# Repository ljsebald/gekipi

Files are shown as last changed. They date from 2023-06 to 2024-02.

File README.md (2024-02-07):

# GekiPi

A controller for games such as O.N.G.E.K.I. based around the Raspberry Pi Pico.

Please note that this is still a Work-In-Progress and isn't really meant for
anyone to actually try to use just yet.

## License

The code in the firmware directory is covered by the MIT License. See
`COPYING.MIT` for more information.

The hardware design in the board directory is covered by the CERN Open Hardware
License Version 2 - Strongly Reciprocal (CERN-OHL-S). See `cern_ohl_s_v2.txt`
for more information.

## Dependencies

The firmware for GekiPi currently only depends on the base Raspberry Pi Pico
SDK, its TinyUSB library, and my version of pn532-lib (which is a git submodule
of the firmware directory).

## Pinouts and GPIO assignments:

Buttons (other than the WAD and Test/Service button) have the following pinout:
1. +5v
2. LED In
3. Signal (active low)
4. LED Out
5. GND

Test/Service have the following pinout:
1. Signal (active low)
2. GND

The WADs have the following pinout:
1. +5v
2. +3.3v
3. LED In
4. Signal (active high, +3.3v)
5. LED Out
6. GND

The NFC connector has the following pinout:
1. +5v
2. +3.3v
3. LED In
4. SDA
5. SCL
6. GND

The Stick connector has the following pinout:
1. +3.3v
2. Analog Signal
3. Analog GND

The LEDs are wired in the following order (all are single LEDs except the WADs):
1. Left Red
2. Left Green
3. Left Blue
4. Right Red
5. Right Green
6. Right Blue
7. Left Menu
8. Right Menu
9. Left WAD
10. Right WAD
11. NFC

The number of LEDs per WAD can be set in the code and defaults to 6.

GPIO pins are assigned as follows on the Pico:
- GPIO0: Left Red
- GPIO1: Left Green
- GPIO2: Left Blue
- GPIO3: Right Red
- GPIO4: Right Green
- GPIO5: Right Blue
- GPIO6: Left Menu
- GPIO7: Right Menu
- GPIO8: Left WAD
- GPIO9: Right WAD
- GPIO16: NFC SDA
- GPIO17: NFC SCL
- GPIO20: LED Output (to 74AHCT125, then Left Red)
- GPIO21: Service
- GPIO22: Test
- GPIO28/ADC2: Stick

All other ADC channels available on a standard Pi Pico board are wired to the
Analog connector (along with +3.3v and Analog GND).

All other GPIO pins (other than those on the Analog connector) are available on
the GPIO connector (along with +3.3v, +5v, and GND)

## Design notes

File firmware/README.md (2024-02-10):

# GekiPi Firmware

A controller for games such as O.N.G.E.K.I. based around the Raspberry Pi Pico.

## USB Devices

This firmware acts as three USB devices when plugged into a PC:

1. A USB CDC device - This is used for debugging purposes and will probably be
   removed at some point.
2. A USB HID Gamepad - All controls are routed through this device, and it
   should appear as any other gamepad to your PC. The gamepad device has two
   axes (only the X axis is used for the stick) and 12 buttons.
3. A USB HID Input/Output device - This is used for controling the LEDs and
   for interacting with the PN532 to read NFC cards. See below for how to
   interact with this device.

## Interaction with HID I/O Device

The HID I/O device for interacting with the LEDs and NFC works on a very simple
command/response format. Commands are a single byte, followed by any data that
the command needs. The following commands are currently supported:

1. LED Update (command = 0x01)
   Command will be immediately followed by the full set of LED colors in RGB
   order. Ordering follows the LED wiring of the board. 1 byte is used per
   color component, so there should be 33 bytes of data total after the command.
2. Begin NFC Polling (command = 0x02, no data)
3. Request NFC Data (command = 0x03, no data)
4. Request control data (command = 0x04, no data)

Each command will respond with a response in the following format:

* 1 byte: command code (this will match the command sent)
* 1 byte: return code (>= 0 for success, < 0 for failure)
* n bytes: any data

Commands 0x01 and 0x02 should always return with a return code of 0 with no
accompanying data unless the command sent is malformed. Command 0x03 will
respond with slightly different data depending on what type of NFC card was
detected. If a MIFARE card was detected (return code 1), the data returned will
be the UID of the card (which may be 4, 7, or 10 bytes long). If a FeliCa card
is detected, the data returned will be the IDm of the card (8 bytes), followed
by the PMm of the card (8 bytes), and the system code of the card (2 bytes). If
polling is still in progress, the return code will be 0. If no card was detected
after the polling period completed, the return code will be 0xfe.

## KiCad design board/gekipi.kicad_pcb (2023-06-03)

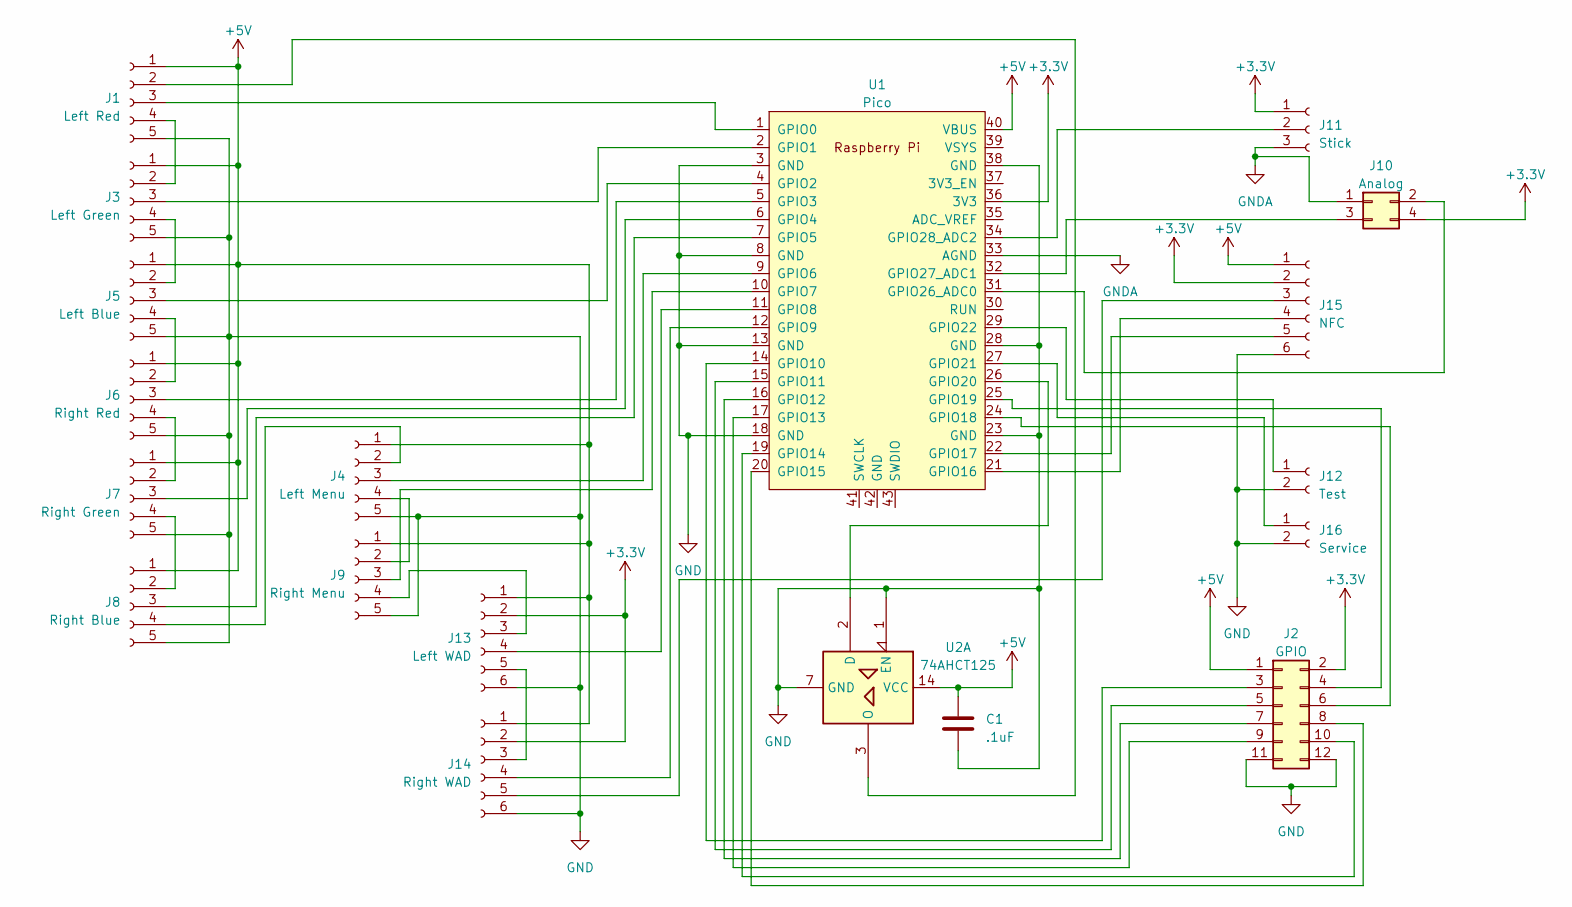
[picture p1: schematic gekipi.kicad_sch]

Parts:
C1: .1uF; C_Rect_L4.0mm_W2.5mm_P2.50mm
J1: Left Red; JST_XH_B5B-XH-A_1x05_P2.50mm_Vertical
J2: GPIO; PinHeader_2x06_P2.54mm_Vertical
J3: Left Green; JST_XH_B5B-XH-A_1x05_P2.50mm_Vertical
J4: Left Menu; JST_XH_B5B-XH-A_1x05_P2.50mm_Vertical
J5: Left Blue; JST_XH_B5B-XH-A_1x05_P2.50mm_Vertical
J6: Right Red; JST_XH_B5B-XH-A_1x05_P2.50mm_Vertical
J7: Right Green; JST_XH_B5B-XH-A_1x05_P2.50mm_Vertical
J8: Right Blue; JST_XH_B5B-XH-A_1x05_P2.50mm_Vertical
J9: Right Menu; JST_XH_B5B-XH-A_1x05_P2.50mm_Vertical
J10: Analog; PinHeader_2x02_P2.54mm_Vertical
J11: Stick; JST_XH_B3B-XH-A_1x03_P2.50mm_Vertical
J12: Test; JST_XH_B2B-XH-A_1x02_P2.50mm_Vertical
J13: Left WAD; JST_XH_B6B-XH-A_1x06_P2.50mm_Vertical
J14: Right WAD; JST_XH_B6B-XH-A_1x06_P2.50mm_Vertical
J15: NFC; JST_XH_B6B-XH-A_1x06_P2.50mm_Vertical
J16: Service; JST_XH_B2B-XH-A_1x02_P2.50mm_Vertical
U1: Pico; RPi_Pico_SMD_TH
U2: 74AHCT125; DIP-14_W7.62mm

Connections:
+3.3V: J2.2, J10.4, J11.1, J13.2, J14.2, J15.2, U1.36 (3V3)
+5V: C1.1, J1.1, J2.1, J3.1, J4.1, J5.1, J6.1, J7.1, J8.1, J9.1, J13.1, J14.1, J15.1, U1.40 (VBUS), U2.14 (VCC)
GND: C1.2, J1.5, J2.11, J2.12, J3.5, J4.5, J5.5, J6.5, J7.5, J8.5, J9.5, J12.2, J13.6, J14.6, J15.6, J16.2, U1.3 (GND), U1.8 (GND), U1.13 (GND), U1.18 (GND), U1.23 (GND), U1.28 (GND), U1.38 (GND), U2.1 (EN), U2.7 (GND)
GNDA: J10.1, J11.3, U1.33 (AGND)
unnamed: J1.2, U2.3 (O)
unnamed: J1.3, U1.1 (GPIO0)
unnamed: J1.4, J3.2
unnamed: J2.3, U1.14 (GPIO10)
unnamed: J2.4, U1.25 (GPIO19)
unnamed: J2.5, U1.15 (GPIO11)
unnamed: J2.6, U1.24 (GPIO18)
unnamed: J2.7, U1.16 (GPIO12)
unnamed: J2.8, U1.20 (GPIO15)
unnamed: J2.9, U1.17 (GPIO13)
unnamed: J2.10, U1.19 (GPIO14)
unnamed: J3.3, U1.2 (GPIO1)
unnamed: J3.4, J5.2
unnamed: J4.2, J8.4
unnamed: J4.3, U1.9 (GPIO6)
unnamed: J4.4, J9.2
unnamed: J5.3, U1.4 (GPIO2)
unnamed: J5.4, J6.2
unnamed: J6.3, U1.5 (GPIO3)
unnamed: J6.4, J7.2
unnamed: J7.3, U1.6 (GPIO4)
unnamed: J7.4, J8.2
unnamed: J8.3, U1.7 (GPIO5)
unnamed: J9.3, U1.10 (GPIO7)
unnamed: J10.2, U1.31 (GPIO26_ADC0)
unnamed: J10.3, U1.32 (GPIO27_ADC1)
unnamed: J11.2, U1.34 (GPIO28_ADC2)
unnamed: J12.1, U1.29 (GPIO22)
unnamed: J9.4, J13.3
unnamed: J13.4, U1.11 (GPIO8)
unnamed: J13.5, J14.3
unnamed: J14.4, U1.12 (GPIO9)
unnamed: J14.5, J15.3
unnamed: J15.4, U1.21 (GPIO16)
unnamed: J15.5, U1.22 (GPIO17)
unnamed: J16.1, U1.27 (GPIO21)
unnamed: U1.26 (GPIO20), U2.2 (D)

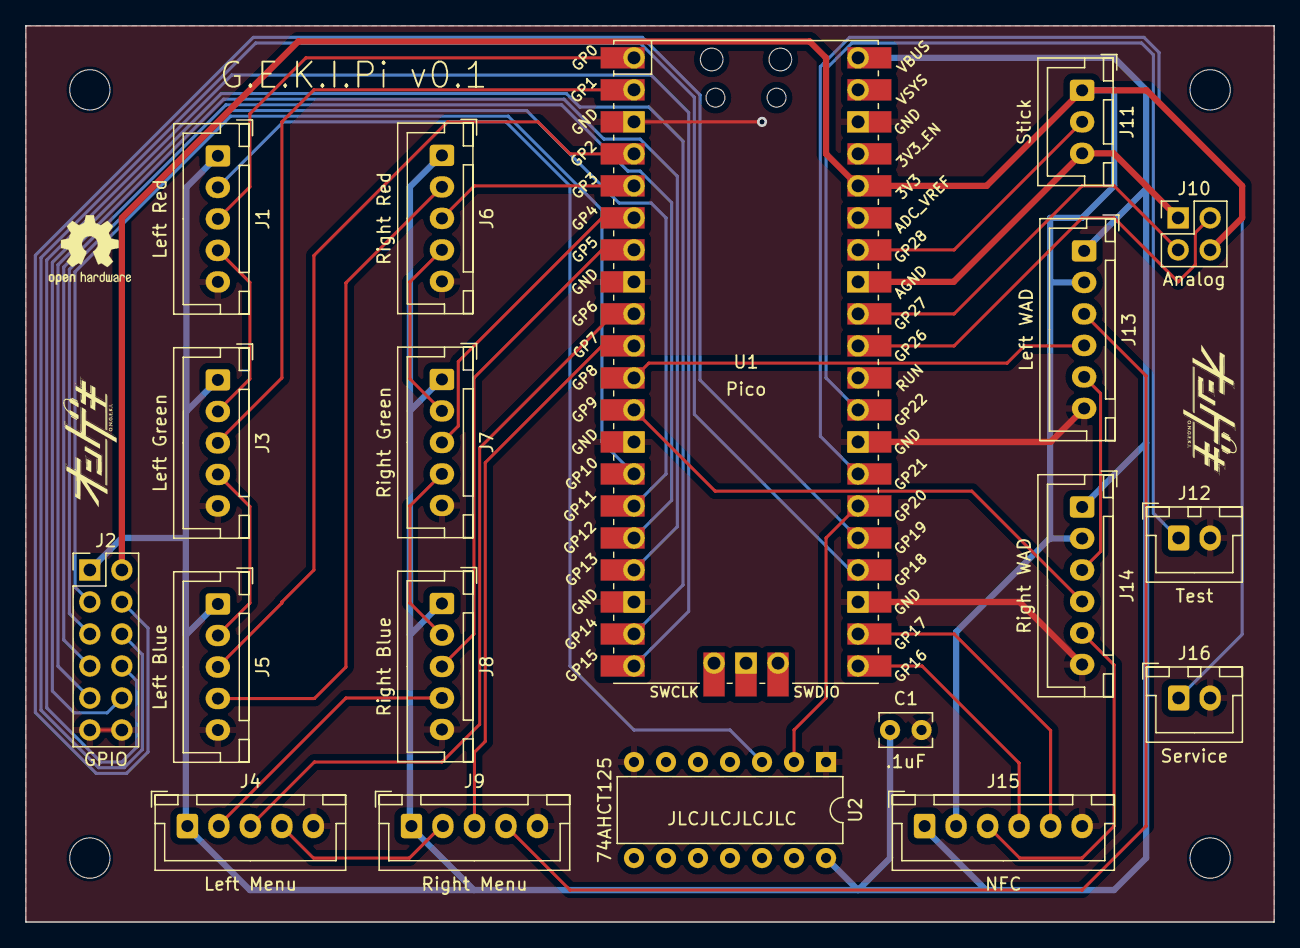
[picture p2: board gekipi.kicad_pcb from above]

Board: 2 copper layers, 99.1 x 71.1 mm, 20 parts (1 on the bottom side), 41 nets.

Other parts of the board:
ongeki-back: LOGO

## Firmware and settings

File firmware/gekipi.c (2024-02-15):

/*
    GekiPi -- An arcade-style controller firmware

    Copyright (C) 2023-2024 Lawrence Sebald

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
    THE SOFTWARE IS PROVIDED "AS IS", WITHOUT WARRANTY OF ANY KIND, EXPRESS OR
    IMPLIED, INCLUDING BUT NOT LIMITED TO THE WARRANTIES OF MERCHANTABILITY,
    FITNESS FOR A PARTICULAR PURPOSE AND NONINFRINGEMENT. IN NO EVENT SHALL THE
    AUTHORS OR COPYRIGHT HOLDERS BE LIABLE FOR ANY CLAIM, DAMAGES OR OTHER
    LIABILITY, WHETHER IN AN ACTION OF CONTRACT, TORT OR OTHERWISE, ARISING
    FROM, OUT OF OR IN CONNECTION WITH THE SOFTWARE OR THE USE OR OTHER DEALINGS
    IN THE SOFTWARE.
*/

#include <stdio.h>
#include <stdlib.h>
#include <string.h>

#include "bsp/board.h"
#include "tusb.h"
#include "pico/stdlib.h"
#include "pico/multicore.h"
#include "hardware/adc.h"
#include "hardware/gpio.h"
#include "hardware/pio.h"
#include "hardware/i2c.h"
#include "pico/util/queue.h"

#include "usb_descriptors.h"
#include "gekipi-config.h"
#include "ws2812.pio.h"
#include "pn532_pico.h"

static uint32_t led_values[TOTAL_LEDS];
#define LED_RGB(r, g, b) ((r << 16) | (g << 24) | (b << 8))

static queue_t mpq;
static PN532 nfc;

static bool nfc_initted = false;
static volatile int nfc_type = 0;
static int mifare_uidlen = 0;
static uint8_t mifare_uid[10];
static uint8_t felica_idm[8];
static uint8_t felica_pmm[8];
static uint8_t felica_syscode[2];
static uint8_t pktbuf[24];

static void init_gpios(void) {
    int i;

    adc_init();

    for(i = 0; i < 12; ++i) {
        gpio_init(gpio_pins[i]);
        gpio_set_dir(gpio_pins[i], GPIO_IN);
        if(gpio_pulls[i] > 0)
            gpio_pull_up(gpio_pins[i]);
        else if(gpio_pulls[i] < 0)
            gpio_pull_down(gpio_pins[i]);
    }

    /* Enable PWM mode for the SMPS to (hopefully) limit ADC noise */
    gpio_init(23);
    gpio_set_dir(23, GPIO_OUT);
    gpio_put(23, 1);

    /* Set up the ADC for the stick */
    adc_gpio_init(STICK_GPIO);

    /* Set up i2c for the NFC reader */
    i2c_init(NFC_I2C, 100 * 1000);
    gpio_set_function(NFC_SDA, GPIO_FUNC_I2C);
    gpio_set_function(NFC_SCL, GPIO_FUNC_I2C);
    gpio_pull_up(NFC_SDA);
    gpio_pull_up(NFC_SCL);

    gpio_init(NFC_IRQ);
    gpio_set_dir(NFC_IRQ, GPIO_IN);
    gpio_pull_up(NFC_IRQ);

    PN532_I2C_Init(&nfc, NFC_I2C, PN532_NO_PIN, PN532_NO_PIN);
}

static inline uint16_t read_buttons(void) {
    int i;
    bool st;
    uint16_t rv = 0;
    uint32_t all = gpio_get_all();

    for(i = 0; i < 12; ++i) {
        if(((all >> gpio_pins[i]) & 1)  == gpio_pressed[i])
            rv |= (1 << i);
    }

    return rv;
}

static inline uint16_t read_stick(void) {
    adc_select_input(STICK_ADC_CHANNEL);

#if STICK_INVERTED == 1
    return (uint16_t)((4095 - adc_read()) << 4);
#else
    return (uint16_t)(adc_read() << 4);
#endif
}

static void hid_task(void) {
    const uint32_t interval_ms = 1;
    static uint32_t start_ms = 0;
    uint16_t state;

    if(board_millis() - start_ms < interval_ms)
        return;

    start_ms += interval_ms;
    state = read_buttons();

    if(tud_suspended() && state) {
        tud_remote_wakeup();
    }
    else {
        gekipi_gamepad_report_t report = { .x = 0, .y = 0, .buttons = state };

        if(!tud_hid_n_ready(GAMEPAD_INSTANCE))
            return;

        report.x = read_stick();
        tud_hid_n_report(GAMEPAD_INSTANCE, 0, &report, sizeof(report));
    }
}

uint16_t tud_hid_get_report_cb(uint8_t iface, uint8_t report_id,
                               hid_report_type_t report_type, uint8_t *buffer,
                               uint16_t reqlen) {
    (void)iface;
    (void)report_id;
    (void)report_type;
    (void)buffer;
    (void)reqlen;

    return 0;
}

#define TASK_LED_UPDATE     1
#define TASK_NFC_INIT       2
#define TASK_NFC_POLL       3

#define REPORT_LED_UPDATE   1
#define REPORT_NFC_POLL     2
#define REPORT_NFC_REQUEST  3
#define REPORT_GP_POLL      4

static void send_rawhid_response(uint8_t inst, uint8_t task, uint8_t retval) {
    const uint8_t pkt[2] = { task, retval };
    tud_hid_n_report(inst, 0, pkt, sizeof(pkt));
}

static void update_led(int led, uint8_t r, uint8_t g, uint8_t b) {
    int i;
    uint32_t color = LED_RGB(r, g, b);

    if(led < 8) {
        led_values[led] = color;
    }
    else if(led == 10) {
        led_values[TOTAL_LEDS - 1] = color;
    }
    else if(led == 8) {
        for(i = 0; i < NUM_WAD_LEDS; ++i) {
            led_values[8 + i] = color;
        }
    }
    else if(led == 9) {
        for(i = 0; i < NUM_WAD_LEDS; ++i) {
            led_values[8 + NUM_WAD_LEDS + i] = color;
        }
    }
}

static void send_rawgp_report(void) {
    gekipi_button_report_t report = {
        .report_id = REPORT_GP_POLL,
        .retcode = 0,
        .lever = read_stick(),
        .buttons = read_buttons()
    };

    tud_hid_n_report(NFC_INSTANCE, 0, &report, sizeof(report));
}

void tud_hid_set_report_cb(uint8_t inst, uint8_t report_id,
                           hid_report_type_t report_type, uint8_t const *buffer,
                           uint16_t bufsize) {
    uint8_t task;
    int i;

    if(inst == NFC_INSTANCE && report_id == 0 && report_type == 0) {
        if(!tud_hid_n_ready(NFC_INSTANCE) || bufsize < 1)
            return;

        switch(buffer[0]) {
            case REPORT_LED_UPDATE:
                printf("Got led update of length %d\n", (int)bufsize);
                if(bufsize != 34) {
                    send_rawhid_response(inst, buffer[0], 0xff);
                    break;
                }

                for(i = 0; i < 11; ++i) {
                    update_led(i, buffer[i * 3 + 1], buffer[i * 3 + 2],
                               buffer[i * 3 + 3]);
                }

                task = TASK_LED_UPDATE;
                queue_add_blocking(&mpq, &task);
                send_rawhid_response(inst, buffer[0], 0);
                break;

            case REPORT_NFC_POLL:
                printf("Got NFC poll request\n");
                nfc_type = -1;
                task = TASK_NFC_POLL;
                queue_add_blocking(&mpq, &task);
                send_rawhid_response(inst, buffer[0], 0);
                break;

            case REPORT_NFC_REQUEST:
                printf("Got NFC request\n");

                if(nfc_type == 0) {
                    send_rawhid_response(inst, buffer[0], 0xfe);
                    break;
                }
                else if(nfc_type == -1) {
                    send_rawhid_response(inst, buffer[0], 0);
                }
                else if(nfc_type == 1) {
                    pktbuf[0] = buffer[0];
                    pktbuf[1] = 1;
                    memcpy(&pktbuf[2], mifare_uid, mifare_uidlen);
                    tud_hid_n_report(inst, 0, pktbuf, mifare_uidlen + 2);
                    break;
                }
                else if(nfc_type == 2) {
                    pktbuf[0] = buffer[0];
                    pktbuf[1] = 2;
                    memcpy(&pktbuf[2], felica_idm, 8);
                    memcpy(&pktbuf[10], felica_pmm, 8);
                    memcpy(&pktbuf[18], felica_syscode, 2);
                    tud_hid_n_report(inst, 0, pktbuf, 20);
                    break;
                }

                send_rawhid_response(inst, buffer[0], 0xff);
                break;

            case REPORT_GP_POLL:
                send_rawgp_report();
                break;

            default:
                printf("Got unknown set report: %d\n", (int)buffer[0]);
                send_rawhid_response(inst, buffer[0], 0xff);
        }
    }
}

void nfc_init(void) {
    int err;
    uint8_t version[4];

    printf("Initializing PN532...\n");

    err = PN532_GetFirmwareVersion(&nfc, version);
    if(err != PN532_STATUS_OK) {
        printf("Failed to get PN532 firmware version\n");
        return;
    }

    printf("Firmware version: %02x%02x%02x%02x\n", version[0], version[1],
           version[2], version[3]);

    err = PN532_SamConfiguration(&nfc);
    if(err != PN532_STATUS_OK) {
        printf("Failed to set SAM configuration\n");
        return;
    }

    nfc_initted = true;
}

/* Use the second core to update the LEDs so that we don't disturb input by
   doing it in the main core. Is this a waste of the core? Probably. But it's
   there, so I might as well... */
void core1_task(void) {
    int i;
    uint8_t task;
    bool polling_nfc = false, polling_felica = false;
    uint32_t poll_timer, last_switch, tmp;

    for(;;) {
        if(queue_try_remove(&mpq, &task)) {
            switch(task) {
                case TASK_LED_UPDATE:
                    for(i = 0; i < TOTAL_LEDS; ++i) {
                        pio_sm_put_blocking(pio0, 0, led_values[i]);
                    }
                    break;

                case TASK_NFC_INIT:
                    if(!nfc_initted) {
                        nfc_init();
                    }
                    break;

                case TASK_NFC_POLL:
                    printf("Beginning NFC poll....\n");
                    if(nfc_initted) {
                        polling_nfc = true;
                        poll_timer = board_millis() + 30 * 1000;
                        last_switch = 0;
                    }
                    break;
            }
        }

        if(polling_nfc) {
            if(gpio_get(NFC_IRQ) == false) {
                if(polling_felica) {
                    uint16_t syscode;

                    printf("Got a FeliCa card!\n");
                    if(PN532_FelicaGet(&nfc, felica_idm, felica_pmm, &syscode,
                                       1) == PN532_STATUS_OK) {
                        felica_syscode[0] = (uint8_t)(syscode >> 8);
                        felica_syscode[1] = (uint8_t)(syscode);
                        polling_nfc = false;
                        nfc_type = 2;
                    }
                }
                else {
                    printf("Got a MIFARE card!\n");
                    mifare_uidlen = PN532_MifareGet(&nfc, mifare_uid, 1);
                    if(mifare_uidlen > 0) {
                        polling_nfc = false;
                        nfc_type = 1;
                    }
                }
            }
            else {
                tmp = board_millis();

                if(tmp > poll_timer) {
                    printf("Polling aborted.\n");
                    polling_nfc = false;
                    nfc_type = 0;
                }
                else if(tmp > last_switch + 5000) {
                    if(polling_felica) {
                        printf("Beginning MIFARE listen\n");
                        PN532_MifareListen(&nfc, PN532_MIFARE_ISO14443A, 1);
                    }
                    else {
                        printf("Beginning FeliCa listen\n");
                        PN532_FelicaListen(&nfc, FELICA_POLL_SYSTEM_CODE_ANY,
                                           FELICA_POLL_SYSTEM_CODE, 1);
                    }

                    polling_felica = !polling_felica;
                    last_switch = tmp;
                }
            }
        }
    }
}

int main(void) {
    uint offset;
    int i;
    uint8_t data;

    stdio_init_all();
    board_init();
    tusb_init();
    init_gpios();

    queue_init(&mpq, 1, 10);

    multicore_launch_core1(core1_task);

    offset = pio_add_program(pio0, &ws2812_program);
    ws2812_program_init(pio0, 0, offset, LED_PIN, 800000, false);

    /* Init the LEDs to an initial state... */
    led_values[0] = LED_RGB(128, 0, 0);
    led_values[1] = LED_RGB(0, 128, 0);
    led_values[2] = LED_RGB(0, 0, 128);
    led_values[3] = LED_RGB(128, 0, 0);
    led_values[4] = LED_RGB(0, 128, 0);
    led_values[5] = LED_RGB(0, 0, 128);
    led_values[6] = LED_RGB(128, 0, 0);
    led_values[7] = LED_RGB(128, 128, 0);
    led_values[TOTAL_LEDS - 1] = LED_RGB(128, 128, 128);

    for(i = 0; i < NUM_WAD_LEDS; ++i) {
        led_values[8 + i] = LED_RGB(128, 0, 128);
        led_values[8 + i + NUM_WAD_LEDS] = LED_RGB(128, 0, 128);
    }

    data = TASK_LED_UPDATE;
    queue_add_blocking(&mpq, &data);

    data = TASK_NFC_INIT;
    queue_add_blocking(&mpq, &data);

    for(;;) {
        tud_task();
        hid_task();
    }

    return 0;
}

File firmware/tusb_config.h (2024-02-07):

/* Adapted from Pico SDK example usb/device/dev_hid_composite */
/*
 * The MIT License (MIT)
 *
 * Copyright (c) 2019 Ha Thach (tinyusb.org)
 *
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
 */

#ifndef _TUSB_CONFIG_H_
#define _TUSB_CONFIG_H_

#ifdef __cplusplus
extern "C" {
#endif

//--------------------------------------------------------------------
// COMMON CONFIGURATION
//--------------------------------------------------------------------

// defined by board.mk
#ifndef CFG_TUSB_MCU
  #error CFG_TUSB_MCU must be defined
#endif

// RHPort number used for device can be defined by board.mk, default to port 0
#ifndef BOARD_DEVICE_RHPORT_NUM
  #define BOARD_DEVICE_RHPORT_NUM     0
#endif

// RHPort max operational speed can defined by board.mk, default to full speed
#ifndef BOARD_DEVICE_RHPORT_SPEED
  #define BOARD_DEVICE_RHPORT_SPEED   OPT_MODE_FULL_SPEED
#endif

// Device mode with rhport and speed defined by board.mk
#if   BOARD_DEVICE_RHPORT_NUM == 0
  #define CFG_TUSB_RHPORT0_MODE     (OPT_MODE_DEVICE | BOARD_DEVICE_RHPORT_SPEED)
#elif BOARD_DEVICE_RHPORT_NUM == 1
  #define CFG_TUSB_RHPORT1_MODE     (OPT_MODE_DEVICE | BOARD_DEVICE_RHPORT_SPEED)
#else
  #error "Incorrect RHPort configuration"
#endif

#ifndef CFG_TUSB_OS
#define CFG_TUSB_OS               OPT_OS_NONE
#endif

// Enable Device stack
#define CFG_TUD_ENABLED       1

// CFG_TUSB_DEBUG is defined by compiler in DEBUG build
// #define CFG_TUSB_DEBUG           0

/* USB DMA on some MCUs can only access a specific SRAM region with restriction on alignment.
 * Tinyusb use follows macros to declare transferring memory so that they can be put
 * into those specific section.
 * e.g
 * - CFG_TUSB_MEM SECTION : __attribute__ (( section(".usb_ram") ))
 * - CFG_TUSB_MEM_ALIGN   : __attribute__ ((aligned(4)))
 */
#ifndef CFG_TUSB_MEM_SECTION
#define CFG_TUSB_MEM_SECTION
#endif

#ifndef CFG_TUSB_MEM_ALIGN
#define CFG_TUSB_MEM_ALIGN          __attribute__ ((aligned(4)))
#endif

//--------------------------------------------------------------------
// DEVICE CONFIGURATION
//--------------------------------------------------------------------

#ifndef CFG_TUD_ENDPOINT0_SIZE
#define CFG_TUD_ENDPOINT0_SIZE    64
#endif

//------------- CLASS -------------//
#define CFG_TUD_HID               2
#define CFG_TUD_CDC               1
#define CFG_TUD_MSC               0
#define CFG_TUD_MIDI              0
#define CFG_TUD_VENDOR            0

// HID buffer size Should be sufficient to hold ID (if any) + Data
#define CFG_TUD_HID_EP_BUFSIZE      64

// CDC buffer size
#define CFG_TUD_CDC_RX_BUFSIZE      64
#define CFG_TUD_CDC_TX_BUFSIZE      64

// HID device configuration
#define CFG_HID_GAMEPAD             1
#define CFG_HID_INOUT               1

#ifdef __cplusplus
}
#endif

#endif /* _TUSB_CONFIG_H_ */

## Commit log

2023-06-02 Modify code to match GekiPi v0.1 board
2023-06-03 Fix name of power supply mode pin
2023-06-03 Switch from 6KRO keyboard emulation to NKRO
2023-06-03 Add KiCad 7.0 project for PCB.
    [gekipi.kicad_pcb, gekipi.kicad_sch]
2023-06-03 Document board layout for v0.1 board.
2023-06-08 Init LEDs.
2023-06-11 Add untested I/O for reading cards and setting LEDs.
2024-01-19 Add GPIO setup and gpio button reporting
2024-01-19 Add code for communicating with LEDs.
2024-01-21 Add i2c setup.
2024-01-23 Set PID/VID.
2024-01-25 Add config for IRQ pin and switch from multicore fifo to a queue instead.
2024-02-05 Split nfc+led and controller functionality into two HID devices.
    Unfortunately, raw hid with multiple descriptors doesn't seem to work very well... So, we separate the two functions into separate hid devices here.
    [gekipi-config.h, gekipi.c, tusb_config.h]
2024-02-05 Make NFC polling switch back and forth between mifare/felica and work.
2024-02-10 Add command to rawhid device to fetch control data.
2024-02-15 Support inverted stick values and fix buttons that are inverted.
    [gekipi-config.h, gekipi.c]
